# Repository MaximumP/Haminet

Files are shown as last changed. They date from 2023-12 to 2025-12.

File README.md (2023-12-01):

# Haminet (Schinken Schrank)

Prototype of a fridge customized to make hams.

Using Software from: (Thanks to the creators ♥)
- https://github.com/9MMMinor/RaspberryPiPicoGFX (copied a few files. Some sort of build will be added later to use the code of the repository)
- https://gist.github.com/SpotlightKid/0a0aac56606286a80f860b116423c94f
- https://micropython.org/

Parts used:
* RaspberryPi Pico
* ILI9225 display
* DHT22 temperature and humidity sensor
* Grove Water Atomization v1.0
* Any 220v 120mm Fan
* a 4channel 220v relay (or four one channel relays)
* four push buttons

Plan to add translations. For now everything is in german

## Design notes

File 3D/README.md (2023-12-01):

# 3D printed parts

For the Atomization to control the humidity a water bottle is used as a storage. I had some issues to get the Atomization work without clogging the module with water.
I cut a sponge to fit into the bottom of the BottleDispenser and put the DispenserTop piece on top of it. You need to remove the silicon part of the atomizer and put it on top of it.
Still experimenting with it, but it works most of the time. I plan to have the atomization ultrasonic module to clip into the top part.

I put a coat of spray paint over the BottleDispenser to make it waterproof.

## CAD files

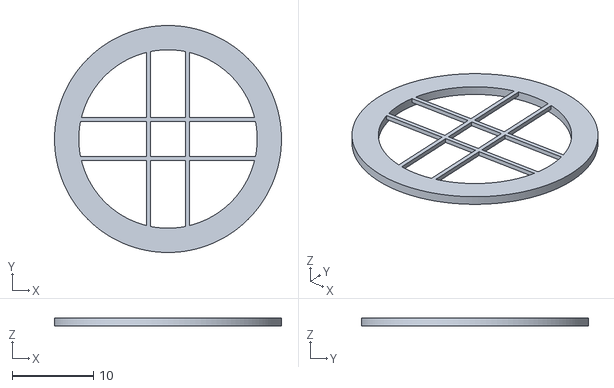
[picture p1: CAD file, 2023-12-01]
3D/DispenserTop.stl
27.9 x 27.9 x 1.00

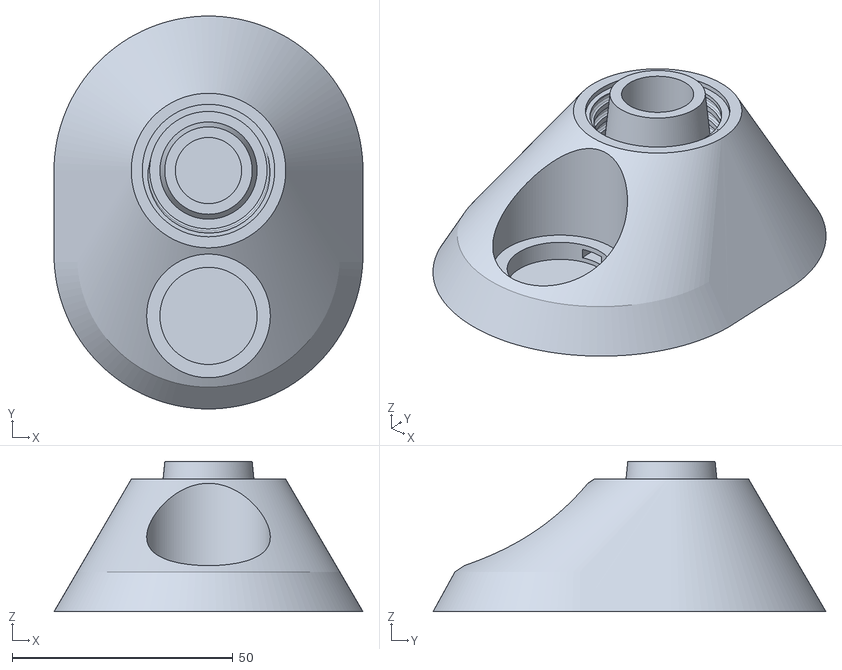
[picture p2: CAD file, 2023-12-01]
3D/BottleDispenser.stl
70.0 x 89.0 x 34.0

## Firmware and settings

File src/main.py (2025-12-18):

from sys import stdin
from select import select
from time import sleep
from framebuf import RGB565, FrameBuffer
from micropython import schedule
from machine import Pin, Timer
from dht import DHT22
from config import Config
from debounce import DebouncedSwitch
from _thread import start_new_thread

from display.pages import ConfigPage, ErrorPage, OverviewPage
from output import Pager
from environment_control import EnvironmentControl

dht = DHT22(Pin(22, Pin.PULL_UP))
timer = Timer(-1)
up = Pin(17, Pin.IN, Pin.PULL_DOWN)
down = Pin(21, Pin.IN, Pin.PULL_DOWN)
edit = Pin(18, Pin.IN, Pin.PULL_DOWN)
page_button = Pin(16, Pin.IN, Pin.PULL_DOWN)
dht_enable = Pin(13, Pin.OUT, value=1)
fan = Pin(12, mode=Pin.OUT, value=0)

config = Config("config.json")
environment_control = EnvironmentControl(
    fan=fan,
    atomizer=Pin(15, mode=Pin.OUT, value=0),
    fridge=Pin(14, mode=Pin.OUT, value=0),
    heater=Pin(28, mode=Pin.OUT, value=0),
    config=config,
)
buffer = bytearray(176 * 220 * 2)  # 2 bytes per pixel (RGB565)
framebuffer = FrameBuffer(buffer, 176, 220, RGB565)
overview_page = OverviewPage(framebuffer, 176, 220)
config_page = ConfigPage(framebuffer, 176, 220, config)
error_page = ErrorPage(framebuffer, 176, 220)
pages = [overview_page, config_page, error_page]
pager = Pager(environment_control, pages, framebuffer, buffer)


def button_handler(pin: Pin):
    if pin == up:
        pager.cursor_up()
    if pin == down:
        pager.cursor_down()
    if pin == edit:
        pager.edit()
    if pin == page_button:
        pager.next_page()


should_run = False
is_running = False


class Scheduler:
    _err_cnt = 0
    _is_measuring = False

    def __init__(self, dht: DHT22, dht_enable: Pin, fan_control):
        # self._running = False
        # self._thread_runing = False
        self._increment_counter = 0
        self._dht_enable = dht_enable
        self._timer = Timer()
        self._measure_timer = Timer()
        self._dht = dht
        self._fan_control = fan_control

    def start(self):
        global should_run
        should_run = True
        self._timer.init(mode=Timer.PERIODIC, period=1000, callback=self._timer_cb)
        self._measure_timer.init(
            mode=Timer.PERIODIC, period=3500, callback=self._run_new_thread
        )
        # start_new_thread(self._run, ())

    def _run_new_thread(self, timer):
        if self._is_measuring:
            return
        self._is_measuring = True
        start_new_thread(self._measure, ())

    def _run(self):
        global should_run
        global is_running
        is_running = True
        while should_run:
            sleep(3)
            self._measure()
            # self._dht.measure()
        is_running = False
        print(f"exited loop: {is_running}")

    def reset_counter(self):
        self._increment_counter = 0

    def counter(self):
        return self._increment_counter

    def stop(self):
        global should_run
        should_run = False
        print("attempt stopping the thread")
        self._timer.deinit()
        while is_running:
            sleep(0.1)
        print("Scheduler stopped")

    def _timer_cb(self, timer):
        self._increment_counter = self._increment_counter + 1
        if self._increment_counter % 60 == 0:
            schedule(self._fan_control, self)

    def _measure(self):
        try:
            if self._dht_enable.value() == 1:
                self._dht.measure()
            else:
                self._dht_enable.value(1)
        except OSError as e:
            self._err_cnt = self._err_cnt + 1
            print(f"{e} {self._err_cnt}")
            self._dht_enable.value(0)
        finally:
            self._is_measuring = False


page_handler = DebouncedSwitch(page_button, button_handler)
up_handler = DebouncedSwitch(up, button_handler)
down_handler = DebouncedSwitch(down, button_handler)
edit_handler = DebouncedSwitch(edit, button_handler)


led_fan = Pin(1, Pin.OUT, value=0)


def fan_control(scheduler: Scheduler):
    if fan.value() == 1:
        if (config.get_fan_on_interval() * 60) <= scheduler.counter():
            fan.value(0)
            led_fan.value(0)
            scheduler.reset_counter()
    else:
        if (config.get_fan_off_interval() * 60) <= scheduler.counter():
            fan.value(1)
            led_fan.value(1)
            scheduler.reset_counter()


def read_serial():
    if stdin in select([stdin], [], [], 0)[0]:
        return stdin.readline().strip()
    return None


scheduler = Scheduler(dht, dht_enable, fan_control)


def main():
    tmp = 0.0
    humidity = 0.0
    log = True
    scheduler.start()
    while True:
        # if scheduler.counter() % 10 == 0:
        #     if log:
        #         print(f"Temperatur:\t\t {dht.temperature()}")
        #         print(f"Luftfeuchtigkeit:\t {dht.humidity()}")
        #         print(f"Soll Temperatur:\t {config.get_target_temperature()}")
        #         print(f"Soll Luftfeuchtigkeit:\t {config.get_target_humidity()}")
        #         print(
        #             f"Lüfter:\t\t\t {'An' if environment_control.get_fan_state() else 'Aus'}"
        #         )
        #         print(f"Lüfter an für:\t\t {config.get_fan_on_interval()} Minuten")
        #         print(f"Lüfter aus für:\t\t {config.get_fan_off_interval()} Minuten\n")
        #         log = False
        # else:
        #     log = True
        overview_page.set_data(
            dht.temperature(),
            dht.humidity(),
            config.get_target_temperature(),
            config.get_target_humidity(),
            environment_control.get_fan_state(),
            config.get_fan_on_interval(),
            config.get_fan_off_interval(),
            scheduler.counter(),
        )
        tmp = dht.temperature()
        humidity = dht.humidity()
        msg = read_serial()
        if msg:
            print(f"Pico received: {msg}")
        try:
            environment_control.control(tmp, humidity)
        except KeyboardInterrupt:
            scheduler.stop()
            print("stopped timer")
        except OSError as e:
            print(e)

        pager.display()


try:
    main()
except KeyboardInterrupt:
    scheduler.stop()
    print("stopped timer")
scheduler.stop()

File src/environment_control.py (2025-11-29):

from machine import Pin
from neopixel import NeoPixel


class EnvironmentControl:
    _COLOR_ACTIVE_FAN = (120, 80, 3)
    _COLOR_ACTIVE_ATOMIZER = (2, 15, 120)
    _COLOR_ACTIVE_COOLING = (2, 112, 120)
    _LED_OFF = (0, 0, 0)

    _FAN_LED_INDEX = 0
    _ATOMIZER_LED_INDEX = 4
    _COOLER_LED_INDEX = 9

    _prev_temperature: None | float = None
    _prev_humidity: None | float = None
    _prev_fan_state: bool
    _prev_fridge_state: bool
    _prev_atomizer_state: bool
    _prev_heater_state: bool
    _neo_pixel: NeoPixel

    def __init__(self, fan, atomizer, fridge, heater, config):
        self._fan = fan
        self._atomizer = atomizer
        self._fridge = fridge
        self._heater = heater
        self._led_atomizer = Pin(6, Pin.OUT, value=0)
        self._led_fridge = Pin(4, Pin.OUT, value=0)
        self._config = config
        # self._neo_pixel = NeoPixel(Pin(0), 10)

    def control(self, temperature: float, humidity: float):
        if not self._prev_humidity:
            self._prev_humidity = humidity
        if not self._prev_temperature:
            self._prev_temperature = temperature
        # self._control_fan(humidity)
        self._control_atomizer(humidity)
        self._control_fridge(temperature)
        # self._control_heater(temperature)
        # self._neo_pixel.write()

        self._prev_temperature = temperature
        self._prev_humidity = humidity
        self._prev_heater_state = self._heater.value()
        self._prev_fan_state = self._fan.value()
        self._prev_fridge_state = self._fridge.value()
        self._prev_atomizer_state = self._atomizer.value()

    def _control_fan(self, humidity: float):
        if humidity >= (
            self._config.get_target_humidity() + self._config.get_humidity_tolerance()
        ) and self._prev_humidity >= (
            self._config.get_target_humidity() + self._config.get_humidity_tolerance()
        ):
            self._fan.value(1)
            # self._neo_pixel[self._FAN_LED_INDEX] = self._COLOR_ACTIVE_FAN
        if (
            humidity <= self._config.get_target_humidity()
            and self._prev_humidity <= self._config.get_target_humidity()
        ):
            self._fan.value(0)
            # self._neo_pixel[self._FAN_LED_INDEX] = self._LED_OFF

    def _control_atomizer(self, humidity: float):
        if humidity <= (
            self._config.get_target_humidity() - self._config.get_humidity_tolerance()
        ):
            self._atomizer.value(1)
            self._led_atomizer.value(1)
            # self._neo_pixel[self._ATOMIZER_LED_INDEX] = self._COLOR_ACTIVE_ATOMIZER
        if humidity >= self._config.get_target_humidity():
            self._atomizer.value(0)
            self._led_atomizer.value(0)
            # self._neo_pixel[self._ATOMIZER_LED_INDEX] = self._LED_OFF

    def _control_fridge(self, temperature: float):
        if temperature >= (
            self._config.get_target_temperature()
            + self._config.get_temperature_tolerance()
        ) and self._prev_temperature >= (
            self._config.get_target_temperature()
            + self._config.get_temperature_tolerance()
        ):
            self._fridge.value(0)
            self._led_fridge.value(1)
            # self._neo_pixel[self._COOLER_LED_INDEX] = self._COLOR_ACTIVE_COOLING
        if (
            temperature <= self._config.get_target_temperature()
            and self._prev_temperature <= self._config.get_target_temperature()
        ):
            self._fridge.value(1)
            self._led_fridge.value(0)
            # self._neo_pixel[self._COOLER_LED_INDEX] = self._LED_OFF

    def _control_heater(self, temperature: float):
        if temperature <= (
            self._config.get_target_temperature()
            - self._config.get_temperature_tolerance()
        ):
            self._heater.value(1)
        if temperature >= (
            self._config.get_target_temperature()
            + self._config.get_temperature_tolerance() / 2
        ):
            self._heater.value(0)

    def get_fan_state(self) -> bool:
        return bool(self._fan.value())

    def get_atomizer_state(self) -> bool:
        return bool(self._atomizer.value())

    def get_fridge_status(self) -> bool:
        return not bool(self._fridge.value())

    def get_heater_status(self) -> bool:
        return bool(self._heater.value())

    def state_changed(self) -> bool:
        return (
            self._prev_fan_state != self._fan.value()
            or self._prev_fridge_state != self._fridge.value()
            or self._prev_heater_state != self._heater.value()
            or self._prev_atomizer_state != self._atomizer.value()
        )

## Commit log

2023-12-01 added prototype stl files for the 3d printed parts
    [BottleDispenser.stl, DispenserTop.stl]
2023-12-02 * added font for icons. only replaced numbers 0-3 * added big TimesNR39x37.py font * formatted output (bigger temperature and humidity values)
    [main.py, output.py]
2023-12-07 Changed some pin new layout on display
2024-01-30 pin mapping for new pcb
2024-12-29 pull up dht sensor
2024-12-29 framebuffer test
2025-01-29 use framebuf interface
2025-07-17 framebuf and pages
    use framebuf interface for ili9225 display
    refactored display output by instroducing pages
2025-07-22 added fan to overview
2025-07-22 fix target humidity
    format target values
    [main.py, pages.py]
2025-07-24 multi-thread
    dht22 on second core
    config page reimplementation
2025-11-01 timed fan
2025-11-01 fixed output, improved startup, fixed typos
    [environment_control.py]
2025-11-29 add led update default config
2025-12-18 run each measurement in a new thread
